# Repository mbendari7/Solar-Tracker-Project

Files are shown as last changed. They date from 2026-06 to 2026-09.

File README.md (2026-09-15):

# Solar Tracker Project

An active solar tracking system designed to optimize photovoltaic energy collection by continuously aligning solar panels with the most intense light source. This repository contains the complete project files, including custom PCB schematics, C++ firmware, and 3D-printable mechanical assemblies. 

The system utilizes closed-loop control, reading environmental light gradients through an array of sensors and actuating motors to maintain optimal panel orientation.

## Project Architecture

The project is divided into three main engineering domains: electrical hardware, mechanical design, and embedded firmware. 

### 1. Hardware and Electronics
The circuit design and PCB layouts were developed using KiCad. The hardware system is responsible for signal acquisition and motor power distribution.

*   **Microcontroller:** Arduino-compatible MCU for processing ADC readings and generating PWM control signals.
*   **Sensors:** Light Dependent Resistors (LDRs) arranged in a directional array with voltage divider networks to measure horizontal and vertical light differentials.
*   **Actuators:** Servos (or stepper motors) to control the pan (azimuth) and tilt (elevation) axes.
*   **Power Management:** Isolated power routing to prevent motor current spikes from inducing noise or brownouts on the logic circuit.
*   **Design Files:** Schematics, PCB layouts, and Gerber files are located in the `hardware/` directory.

### 2. Embedded Firmware
The control logic is written entirely in C++ and focuses on efficiency and preventing mechanical jitter. 

*   **Platform:** C++ (compiled via Arduino IDE or PlatformIO).
*   **Control Loop:** The firmware continuously polls the analog pins connected to the LDRs, calculates the light differential across the axes, and updates motor positions accordingly.
*   **Hysteresis Implementation:** A software-defined deadband is included to filter out minor lighting fluctuations (like passing clouds or sensor noise). This prevents continuous, unnecessary motor twitching, which saves power and reduces mechanical wear.
*   **Source Files:** All code, including headers and main operational logic, can be found in the `firmware/` directory.

### 3. Mechanical Design
The physical chassis is custom-designed for structural rigidity and minimal weight, ensuring the motors do not experience excessive torque loads. 

*   **Fabrication:** Designed for Fused Deposition Modeling (FDM) 3D printing. PLA or PETG is recommended for durability.
*   **Components:** Includes the base mount, azimuth rotation brackets, elevation tilt brackets, and the solar panel mounting plate. A cross-shaped LDR shadow shield is also included to cast distinct shadows over the sensors when the panel is not perfectly aligned.
*   **CAD Files:** STL files and step files are provided in the `cad/` directory.

## Repository Structure

├── cad/                  # 3D printable models (.STL files for chassis and mounts)
├── hardware/             # KiCad schematic files, PCB layouts, and gerbers
├── firmware/             # C++ source code for the microcontroller
├── docs/                 # Wiring diagrams and supplemental documentation
└── README.md             # Project overview

## Setup and Assembly

### Mechanical Assembly
1. Print all components located in the `cad/` directory with a minimum of 20% infill for structural integrity.
2. Assemble the base and mount the azimuth motor.
3. Attach the elevation bracket and corresponding motor.
4. Mount the LDR array and attach the cross-shield to ensure accurate differential shading.

### Electronics Wiring
1. Open the KiCad schematics in the `hardware/` folder to review the pinout.
2. Wire the LDR voltage dividers to the analog input pins of your MCU.
3. Connect the motor control lines to the designated PWM output pins.
4. Ensure the motors are powered by an adequate external power supply with a common ground shared with the MCU.

### Firmware Flashing
1. Open the `firmware/` directory in your preferred IDE.
2. Verify that the assigned pin definitions in the header files match your physical wiring.
3. Adjust the threshold and delay variables if your specific ambient lighting environment requires more or less sensitivity.
4. Compile and upload the code to the microcontroller.

## Future Improvements

*   Implementation of real-time clock (RTC) modules for predictive solar tracking based on time of day and geographical coordinates.
*   Integration of current and voltage sensors to log actual power generation data.
*   Migrating from servo motors to precision stepper motors for larger panel handling.

## License

This project is open-source. Feel free to fork the repository, submit pull requests, or adapt the designs for your own applications.

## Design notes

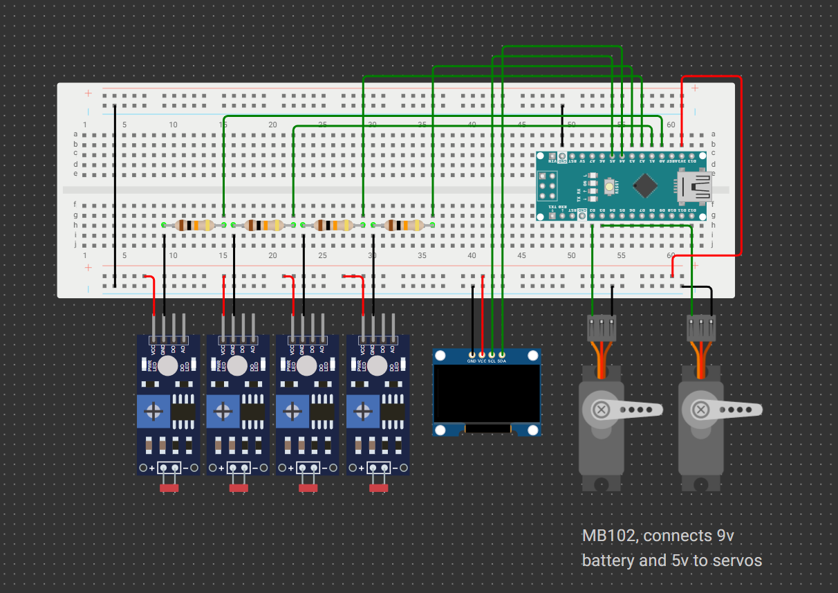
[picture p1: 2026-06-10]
Diagrams/Visual Circuit Diagram.png

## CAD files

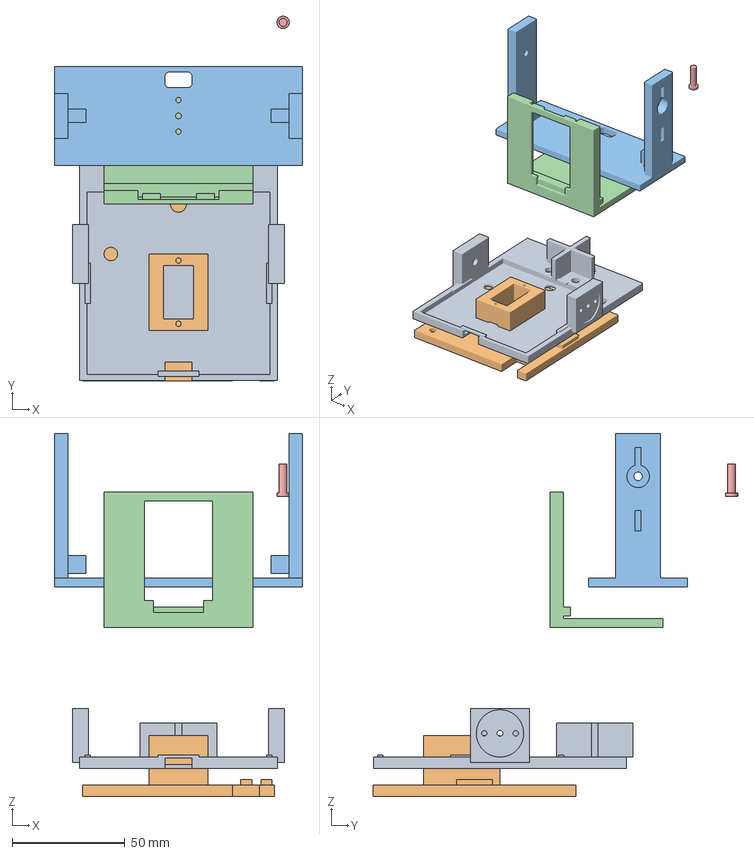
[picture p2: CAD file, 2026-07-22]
CAD and STL/CSP_solar_tracker_FINAL_all-in-one (5).3mf
110.0 x 161.7 x 161.0 mm
solar_tracker_FINAL_all-in-one (5).stl
solar_tracker_FINAL_all-in-one (5).stl 1
solar_tracker_FINAL_all-in-one (5).stl 2
solar_tracker_FINAL_all-in-one (5).stl 3
solar_tracker_FINAL_all-in-one (5).stl 4

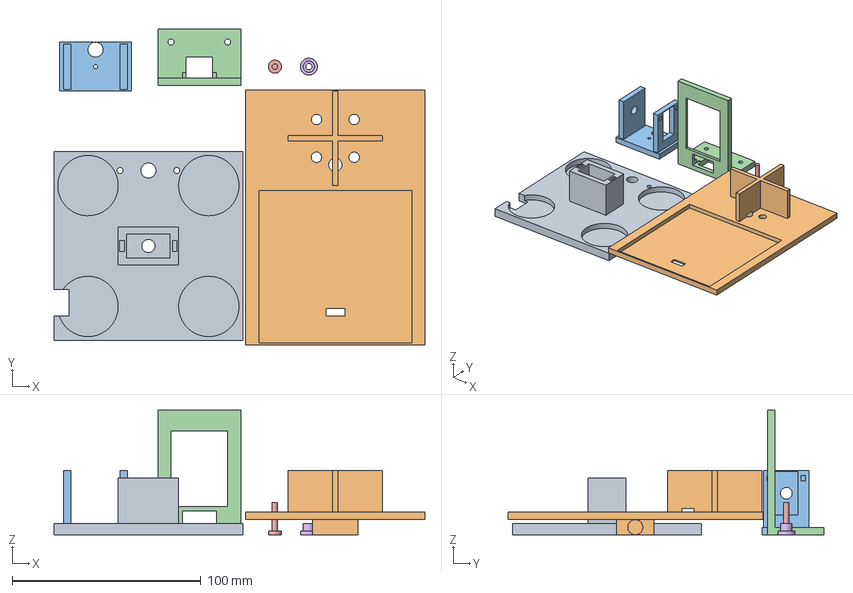
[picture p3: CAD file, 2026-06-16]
CAD and STL/solar_tracker_ALL.step
196.5 x 167.5 x 66.0 mm

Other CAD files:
CAD and STL/solar_tracker_ALL.SLDASM

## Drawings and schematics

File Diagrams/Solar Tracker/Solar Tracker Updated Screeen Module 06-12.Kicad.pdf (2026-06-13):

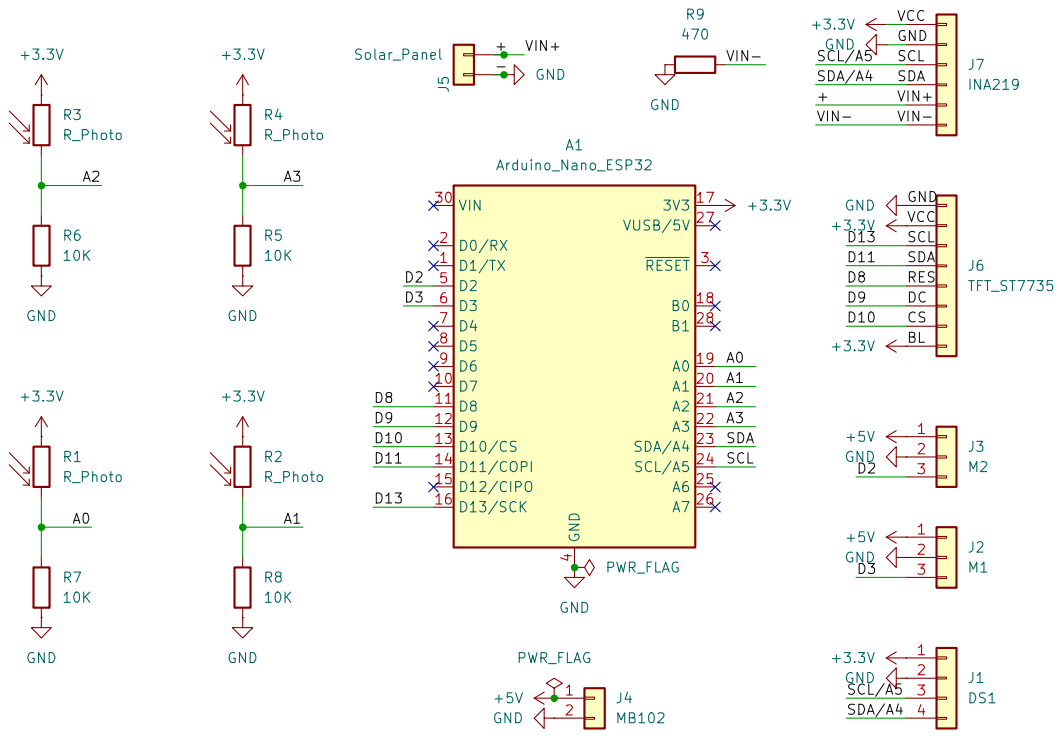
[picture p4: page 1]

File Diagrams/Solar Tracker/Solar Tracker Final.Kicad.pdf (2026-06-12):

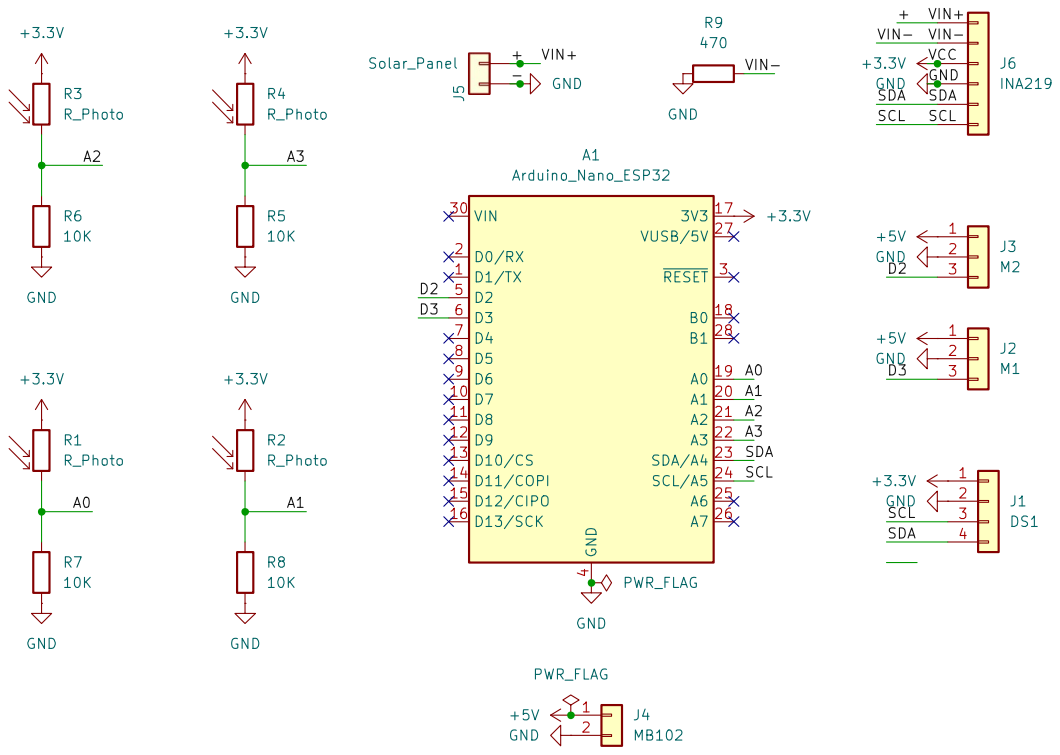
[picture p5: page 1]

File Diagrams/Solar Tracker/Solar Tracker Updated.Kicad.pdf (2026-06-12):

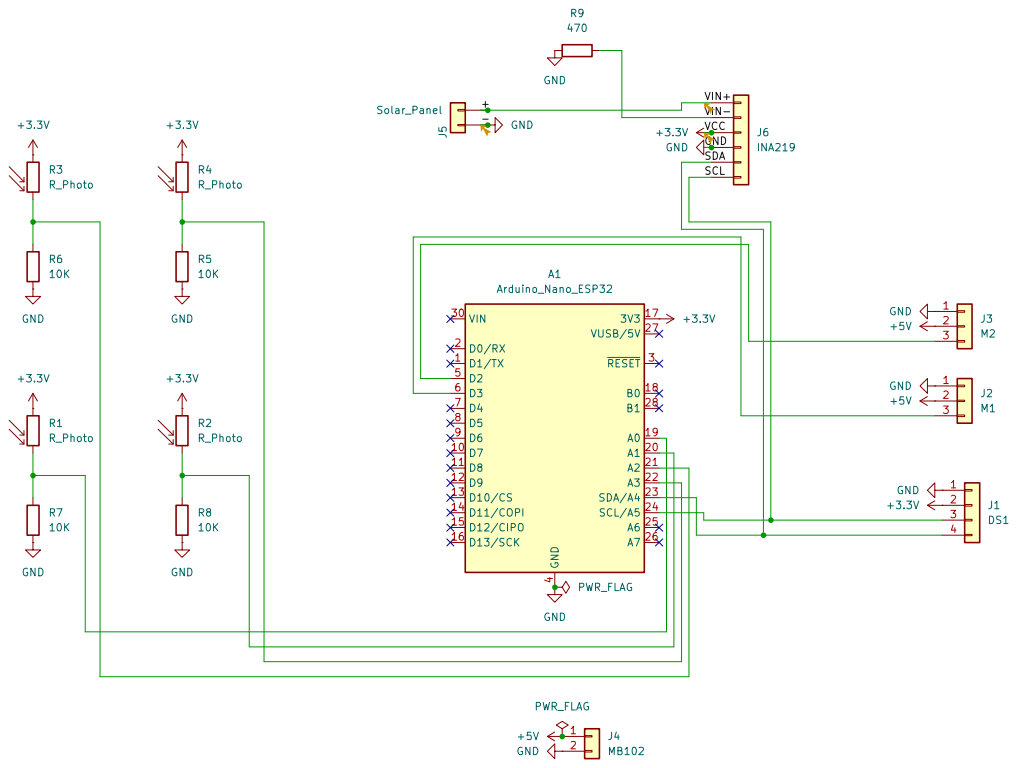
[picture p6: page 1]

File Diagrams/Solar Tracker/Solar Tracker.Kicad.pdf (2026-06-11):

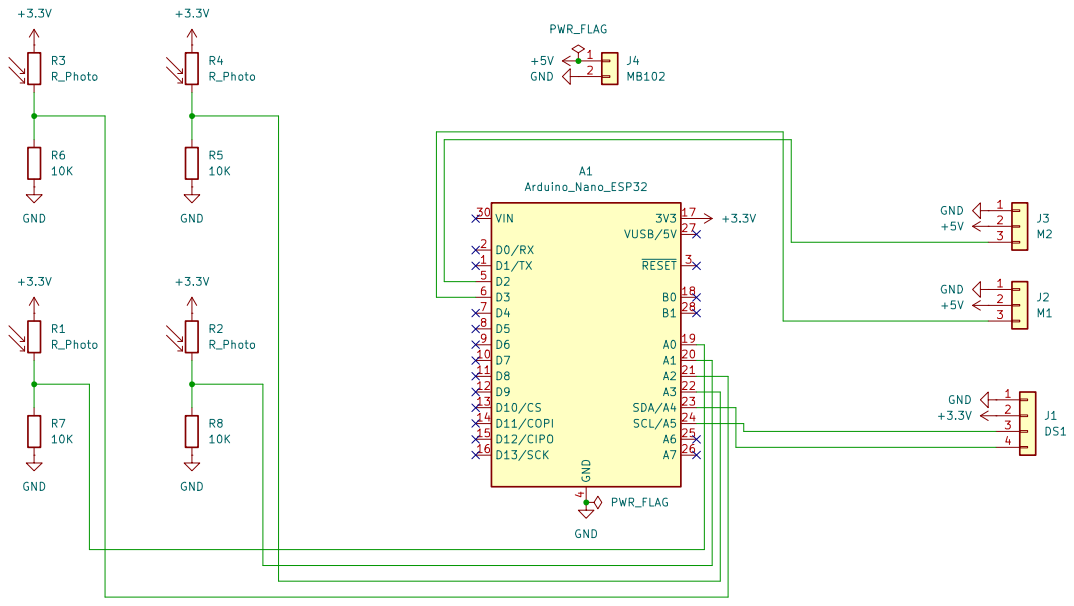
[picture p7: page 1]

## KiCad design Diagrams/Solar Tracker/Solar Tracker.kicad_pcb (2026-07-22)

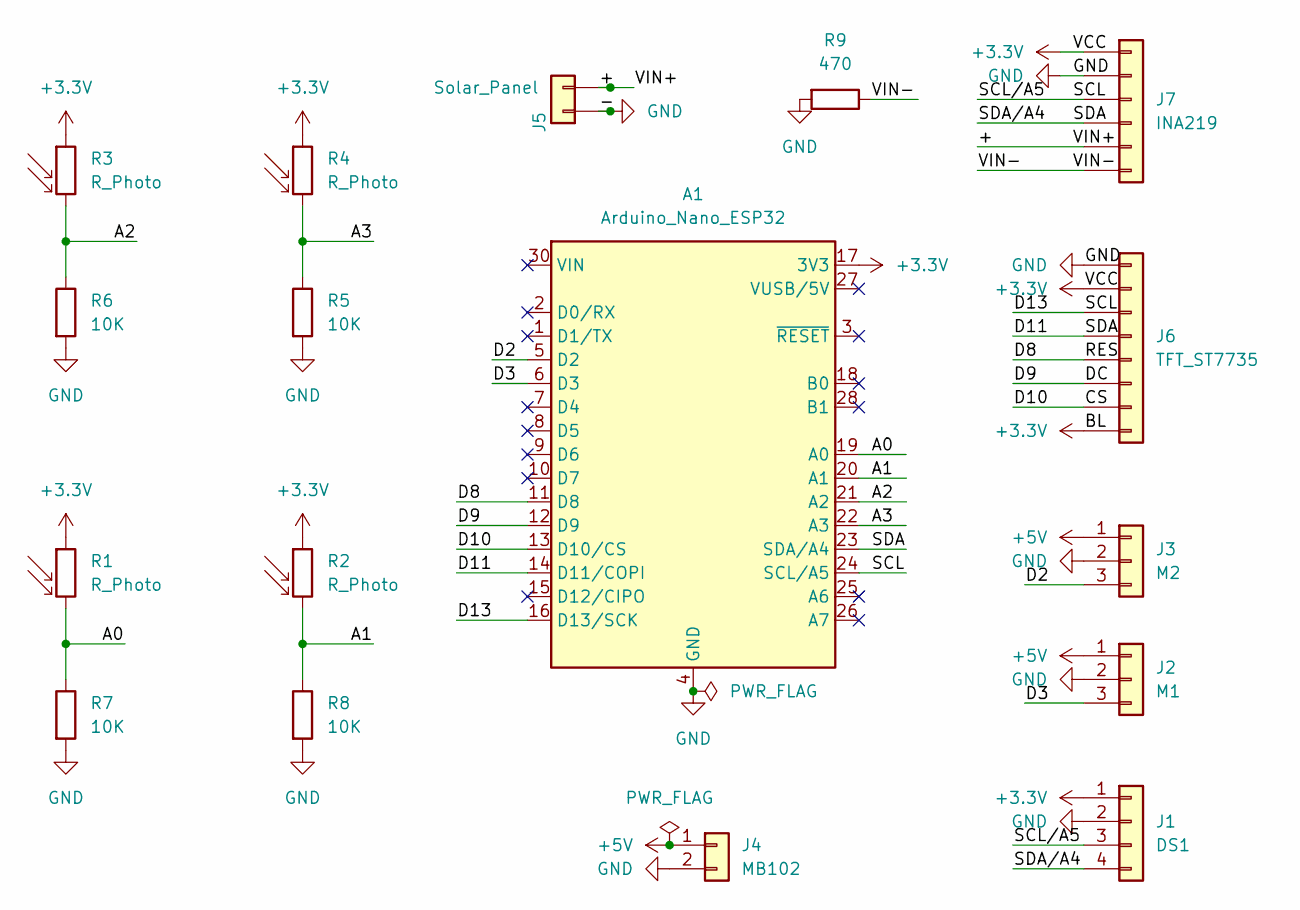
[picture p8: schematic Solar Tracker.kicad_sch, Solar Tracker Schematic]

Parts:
A1: Arduino_Nano_ESP32; Arduino_Nano
J1: DS1; PinHeader_1x04_P2.54mm_Vertical
J2: M1; PinHeader_1x03_P2.54mm_Vertical
J3: M2; PinHeader_1x03_P2.54mm_Vertical
J4: MB102; TerminalBlock_Phoenix_MKDS-1,5-2-5.08_1x02_P5.08mm_Horizont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
J5: Solar_Panel; TerminalBlock_Phoenix_MKDS-1,5-2-5.08_1x02_P5.08mm_Horizont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
J6: TFT_ST7735; PinHeader_1x08_P2.54mm_Vertical
J7: INA219; PinHeader_1x06_P2.54mm_Vertical
R1, R2, R3, R4: R_Photo; R_LDR_5.1x4.3mm_P3.4mm_Vertical
R5, R6, R7, R8: 10K; R_Axial_DIN0207_L6.3mm_D2.5mm_P10.16mm_Horizontal
R9: 470; R_Axial_DIN0207_L6.3mm_D2.5mm_P10.16mm_Horizontal

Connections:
+3.3V: A1.17 (3V3), J1.1, J6.2, J6.8, J7.1, R1.1, R2.1, R3.1, R4.1
+5V: J2.1, J3.1, J4.1
/+: J5.2, J7.5
/A0: A1.19 (A0), R1.2, R7.1
/A1: A1.20 (A1), R2.2, R8.1
/A2: A1.21 (A2), R3.2, R6.1
/A3: A1.22 (A3), R4.2, R5.1
/CS: A1.13 (D10/CS), J6.7
/D2: A1.5 (D2), J3.3
/D3: A1.6 (D3), J2.3
/D8: A1.11 (D8), J6.5
/D9: A1.12 (D9), J6.6
/D11: A1.14 (D11/COPI), A1.23 (SDA/A4), J1.4, J6.4, J7.4
/D13: A1.16 (D13/SCK), A1.24 (SCL/A5), J1.3, J6.3, J7.3
/VIN-: J7.6, R9.1
GND: A1.4 (GND), A1.29 (GND), J1.2, J2.2, J3.2, J4.2, J5.1, J6.1, J7.2, R5.2, R6.2, R7.2, R8.2, R9.2

Board: 2 copper layers, 17 parts (0 on the bottom side), 16 nets, no tracks yet.

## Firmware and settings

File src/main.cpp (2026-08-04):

/*
  DUAL-AXIS SOLAR TRACKER + POWER LOGGER + WIFI CONTROL PANEL
  Arduino Nano ESP32
*/

#include <string.h>
#include <Wire.h>
#include <SPI.h>
#include <Adafruit_GFX.h>
#include <Adafruit_ST7735.h>
#include <Adafruit_INA219.h>
#include <ESP32Servo.h>
#include <WiFi.h>
#include <WebServer.h>

// --- REVERTED TO EXPLICIT GPIO NUMBERS ---
const int PIN_TL = 1, PIN_TR = 2, PIN_BL = 3, PIN_BR = 4;
const int PAN_PIN = 5, TILT_PIN = 6;
#define TFT_CS 21
#define TFT_DC 18
#define TFT_RST 17
#define TFT_BL 10
#define TFT_SCLK 48
#define TFT_MOSI 38
#define I2C_SDA 11
#define I2C_SCL 12
#define TFT_TAB INITR_BLACKTAB
#define RAIL33_PIN 13
#define RAIL5_PIN 14
#define RAIL5_FACTOR 3.136f
// -----------------------------------------

Adafruit_ST7735 tft = Adafruit_ST7735(TFT_CS, TFT_DC, TFT_MOSI, TFT_SCLK, TFT_RST);
Adafruit_INA219 ina219;
Servo panServo, tiltServo;

const char *AP_SSID = "SolarTracker";
const char *AP_PASS = "track1234";
WebServer server(80);

const int SETTLE_MS = 20, ANGLE_MIN = 10, ANGLE_MAX = 170, PAN_DIR = +1, TILT_DIR = +1;
const int STALL_CYCLES = 40, PARK_PAN = ANGLE_MIN, PARK_TILT = 60;
const unsigned long DRAW_EVERY = 400;
const unsigned long SERIAL_EVERY = 1000;

int deadzone = 60;
int stepDeg = 1;
int darkLevel = 350;
int smoothPct = 30;
int fixedPan = 90;
int fixedTilt = 90;

enum Mode
{
  AUTO,
  FIXEDMODE,
  MANUAL
};
Mode mode = AUTO;
int manualPan = 90, manualTilt = 90;
bool isNight = false;
const char *stateLabel = "TRACKING";

int panAngle = 90, tiltAngle = 90;
int rawTL, rawTR, rawBL, rawBR;
float tl = 0, tr = 0, bl = 0, br = 0;
int hErr, vErr, panStall = 0, tiltStall = 0;
bool panStalled = false, tiltStalled = false;

float busV = 0, current_mA = 0, power_mW = 0;
bool inaOK = false;
char i2cList[64] = "";
bool servosAttached = false;
float rail33 = 0, rail5 = 0;
double energyTrack_mWh = 0, energyFixed_mWh = 0, msTrack = 0, msFixed = 0;
unsigned long lastEnergyMs = 0, lastDrawMs = 0, lastSerialMs = 0;
bool layoutDrawn = false;

void readSensors();
void updateDisplay();
void i2cScan();
void serialStatus();
void drawLayout();
uint16_t stateColor();
float gainPct();
const char *modeName();
void handleRoot();
void handleData();
void handleMode();
void handleMove();
void handleSet();
void handleReset();
void handleServoTest();

const char PAGE[] = R"HTML(
<!doctype html><html><head><meta charset=utf-8>
<meta name=viewport content="width=device-width,initial-scale=1"><title>Solar Tracker</title>
<style>
*{box-sizing:border-box}body{font-family:system-ui,Segoe UI,Roboto,sans-serif;
background:linear-gradient(160deg,#0a0e15,#0f1722);color:#e6eef7;margin:0 auto;padding:18px;max-width:560px}
h1{font-size:20px;margin:0;display:flex;align-items:center;gap:8px}
.sub{color:#6f8398;font-size:12px;margin:2px 0 14px}
.badge{font-size:12px;font-weight:800;padding:4px 10px;border-radius:20px;color:#06222a}
.card{background:#121b27;border:1px solid #1e2c3c;border-radius:14px;padding:16px;margin:12px 0;box-shadow:0 4px 14px rgba(0,0,0,.25)}
.label{color:#7d92a6;font-size:12px;text-transform:uppercase;letter-spacing:.5px}
.big{font-size:40px;font-weight:800;color:#39d98a;line-height:1.1}.unit{font-size:16px;color:#7d92a6;font-weight:600}
.gain{font-size:30px;font-weight:800;color:#f5b301}
.row{display:flex;justify-content:space-between;align-items:center;margin:7px 0;font-size:14px}.k{color:#7d92a6}.v{font-weight:600}
canvas{width:100%;height:90px;display:block;margin-top:10px}
.modes{display:flex;gap:8px}.modes button{flex:1;padding:11px;border:1px solid #27384b;border-radius:10px;background:#16212f;color:#cfe0f0;font-weight:700;font-size:14px}
.modes button.on{background:#39d98a;color:#06222a;border-color:#39d98a}
.slider{margin:12px 0}.slider .top{display:flex;justify-content:space-between;font-size:13px;margin-bottom:4px}
input[type=range]{width:100%;accent-color:#39d98a}
.btn{width:100%;padding:12px;border:0;border-radius:10px;background:#27384b;color:#cfe0f0;font-weight:700;font-size:14px;margin-top:6px}
.hide{display:none}.grid{display:grid;grid-template-columns:1fr 1fr;gap:10px;margin-top:8px}
.stat{background:#0e1722;border:1px solid #1c2a3a;border-radius:10px;padding:10px}.stat .n{font-size:18px;font-weight:700}
</style></head><body>
<h1>&#9728;&#65039; Solar Tracker <span id=badge class=badge>--</span></h1>
<div class=sub>live control panel &middot; 192.168.4.1</div>

<div class=card><div class=label>Power now</div>
<div class=big id=power>--<span class=unit> mW</span></div>
<canvas id=spark width=520 height=90></canvas></div>

<div class=card>
<div class=modes>
<button id=mAuto onclick="setMode('auto')">Auto</button>
<button id=mFixed onclick="setMode('fixed')">Fixed</button>
<button id=mManual onclick="setMode('manual')">Manual</button></div>
<div id=manual class=hide>
<div class=slider><div class=top><span class=k>Pan</span><span id=mpL>90&deg;</span></div>
<input type=range id=mp min=10 max=170 value=90 oninput="move()"></div>
<div class=slider><div class=top><span class=k>Tilt</span><span id=mtL>90&deg;</span></div>
<input type=range id=mt min=10 max=170 value=90 oninput="move()"></div></div></div>

<div class=card><div class=label>Tracking vs Fixed</div>
<div class=gain id=gain>--</div>
<div class=grid>
<div class=stat><div class=k>Track avg</div><div class=n id=pT>--</div></div>
<div class=stat><div class=k>Fixed avg</div><div class=n id=pF>--</div></div>
<div class=stat><div class=k>Energy track</div><div class=n id=eT>--</div></div>
<div class=stat><div class=k>Energy fixed</div><div class=n id=eF>--</div></div></div>
<button class=btn onclick="reset()">Reset comparison</button></div>

<div class=card>
<div class=row><span class=k>State</span><span class=v id=state>--</span></div>
<div class=row><span class=k>Voltage</span><span class=v id=volts>--</span></div>
<div class=row><span class=k>Pan / Tilt</span><span class=v id=ang>--</span></div>
<div class=row><span class=k>Sensors TL TR BL BR</span><span class=v id=sens>--</span></div></div>

<div class=card><div class=label>Diagnostics</div>
<div class=row><span class=k>I2C devices found</span><span class=v id=i2c>--</span></div>
<div class=row><span class=k>INA219</span><span class=v id=ina>--</span></div>
<div class=row><span class=k>Servos attached</span><span class=v id=sv>--</span></div>
<div class=row><span class=k>3.3V rail (wire to A6)</span><span class=v id=r33>--</span></div>
<div class=row><span class=k>5V rail (divider to A7)</span><span class=v id=r5>--</span></div>
<button class=btn onclick="servoTest()">Test servos now (forced sweep)</button></div>

<div class=card><div class=label>Tuning (live)</div>
<div class=slider><div class=top><span class=k>Deadzone</span><span id=dzL>--</span></div>
<input type=range id=dz min=5 max=300 oninput="setv('deadzone','dz','dzL','')"></div>
<div class=slider><div class=top><span class=k>Step size</span><span id=stL>--</span></div>
<input type=range id=st min=1 max=5 oninput="setv('step','st','stL','')"></div>
<div class=slider><div class=top><span class=k>Smoothing</span><span id=smL>--</span></div>
<input type=range id=sm min=5 max=90 oninput="setv('smooth','sm','smL','%')"></div>
<div class=slider><div class=top><span class=k>Night level</span><span id=dkL>--</span></div>
<input type=range id=dk min=0 max=2000 oninput="setv('dark','dk','dkL','')"></div>
<div class=slider><div class=top><span class=k>Fixed pan</span><span id=fpL>--</span></div>
<input type=range id=fp min=10 max=170 oninput="setv('fpan','fp','fpL','&deg;')"></div>
<div class=slider><div class=top><span class=k>Fixed tilt</span><span id=ftL>--</span></div>
<input type=range id=ft min=10 max=170 oninput="setv('ftilt','ft','ftL','&deg;')"></div></div>

<script>
let hist=[],first=true,last={},$=id=>document.getElementById(id);
const bc={TRACKING:'#39d98a',NIGHT:'#6aa6ff',FIXED:'#f5b301',MANUAL:'#ff7ac6'};
async function tick(){try{
let d=await(await fetch('/data')).json();last=d;
$('power').innerHTML=d.power.toFixed(1)+'<span class=unit> mW</span>';
$('badge').textContent=d.state;$('badge').style.background=bc[d.state]||'#7d92a6';
$('gain').textContent=(d.gain>=0?'+':'')+d.gain.toFixed(1)+'%';
$('pT').textContent=d.pTrack.toFixed(1)+' mW';$('pF').textContent=d.pFixed.toFixed(1)+' mW';
$('eT').textContent=d.eTrack.toFixed(2)+' mWh';$('eF').textContent=d.eFixed.toFixed(2)+' mWh';
$('state').textContent=d.state+(d.stall?'  (stall)':'');
$('volts').textContent=d.volts.toFixed(2)+' V';$('ang').textContent=d.pan+'\u00b0 / '+d.tilt+'\u00b0';
$('sens').textContent=d.s.join('  ');
$('i2c').textContent=d.i2c;
$('ina').textContent=d.ina?'FOUND':'NOT FOUND';$('ina').style.color=d.ina?'#39d98a':'#ff6b6b';
$('sv').textContent=d.sv?'yes':'NO';$('sv').style.color=d.sv?'#39d98a':'#ff6b6b';
$('r33').textContent=d.r33<0.3?'not wired':d.r33.toFixed(2)+' V';
$('r33').style.color=d.r33<0.3?'#8b98a5':(d.r33>3.0?'#39d98a':'#ff6b6b');
$('r5').textContent=d.r5<0.5?'not wired':d.r5.toFixed(2)+' V';
$('r5').style.color=d.r5<0.5?'#8b98a5':(d.r5>4.6?'#39d98a':'#ff6b6b');
['mAuto','mFixed','mManual'].forEach(x=>$(x).classList.remove('on'));
$({auto:'mAuto',fixed:'mFixed',manual:'mManual'}[d.mode]).classList.add('on');
$('manual').classList.toggle('hide',d.mode!='manual');
if(first){
 $('dz').value=d.deadzone;$('dzL').textContent=d.deadzone;
 $('st').value=d.step;$('stL').textContent=d.step;
 $('sm').value=d.smooth;$('smL').textContent=d.smooth+'%';
 $('dk').value=d.dark;$('dkL').textContent=d.dark;
 $('fp').value=d.fpan;$('fpL').innerHTML=d.fpan+'&deg;';
 $('ft').value=d.ftilt;$('ftL').innerHTML=d.ftilt+'&deg;';
 first=false;}
hist.push(d.power);if(hist.length>120)hist.shift();draw();
}catch(e){}}
function draw(){let c=$('spark'),x=c.getContext('2d'),w=c.width,h=c.height;
x.clearRect(0,0,w,h);let m=Math.max(1,...hist);x.strokeStyle='#39d98a';x.lineWidth=2;x.beginPath();
hist.forEach((v,i)=>{let px=i/119*w,py=h-(v/m)*(h-8)-4;i?x.lineTo(px,py):x.moveTo(px,py);});x.stroke();}
function setMode(m){fetch('/mode?m='+m);
 if(m=='manual'&&last.pan!=null){$('mp').value=last.pan;$('mt').value=last.tilt;
  $('mpL').innerHTML=last.pan+'&deg;';$('mtL').innerHTML=last.tilt+'&deg;';}}
function move(){let p=$('mp').value,t=$('mt').value;
 $('mpL').innerHTML=p+'&deg;';$('mtL').innerHTML=t+'&deg;';fetch('/move?pan='+p+'&tilt='+t);}
function setv(key,sid,lid,suf){let v=$(sid).value;$(lid).innerHTML=v+suf;fetch('/set?k='+key+'&v='+v);}
function reset(){fetch('/reset');}
function servoTest(){fetch('/servotest');}
setInterval(tick,1000);tick();
</script></body></html>
)HTML";

void setup()
{
  Serial.begin(115200);
  delay(3000);

  Serial.println("Booting up...");
  analogReadResolution(12);
  pinMode(TFT_BL, OUTPUT);
  digitalWrite(TFT_BL, HIGH);

  Wire.begin(I2C_SDA, I2C_SCL);
  i2cScan();
  inaOK = ina219.begin();
  if (inaOK)
  {
    ina219.setCalibration_16V_400mA();
    Serial.println("INA219 ready (16V / 400mA range)");
  }
  else
    Serial.println("INA219 NOT FOUND -- check SDA on A4, SCL on A5, VCC on 3.3V");

  tft.initR(TFT_TAB);
  tft.setRotation(3);

  Serial.println("Display test: red, green, blue...");
  tft.fillScreen(ST77XX_RED);
  delay(350);
  tft.fillScreen(ST77XX_GREEN);
  delay(350);
  tft.fillScreen(ST77XX_BLUE);
  delay(350);
  tft.fillScreen(ST77XX_BLACK);
  tft.setTextColor(ST77XX_YELLOW);
  tft.setTextSize(2);
  tft.setCursor(8, 28);
  tft.print("SOLAR");
  tft.setTextSize(1);
  tft.setTextColor(ST77XX_WHITE);
  tft.setCursor(8, 56);
  tft.print("WiFi: ");
  tft.print(AP_SSID);
  tft.setCursor(8, 70);
  tft.print("http://192.168.4.1");

  ESP32PWM::allocateTimer(0);
  ESP32PWM::allocateTimer(1);
  ESP32PWM::allocateTimer(2);
  ESP32PWM::allocateTimer(3);
  panServo.setPeriodHertz(50);
  tiltServo.setPeriodHertz(50);
  panServo.attach(PAN_PIN, 500, 2400);
  tiltServo.attach(TILT_PIN, 500, 2400);
  servosAttached = panServo.attached() && tiltServo.attached();
  Serial.println(servosAttached ? "Servos attached" : "SERVO ATTACH FAILED");
  panServo.write(panAngle);
  tiltServo.write(tiltAngle);

  WiFi.softAP(AP_SSID, AP_PASS);
  server.on("/", handleRoot);
  server.on("/data", handleData);
  server.on("/mode", handleMode);
  server.on("/move", handleMove);
  server.on("/set", handleSet);
  server.on("/reset", handleReset);
  server.on("/servotest", handleServoTest);
  server.begin();
  layoutDrawn = false;

  lastEnergyMs = millis();
  delay(1200);
}

void loop()
{
  readSensors();
  float avg = (tl + tr + bl + br) / 4.0;

  if (inaOK)
  {
    busV = ina219.getBusVoltage_V();
    current_mA = ina219.getCurrent_mA();
    power_mW = ina219.getPower_mW();
    if (power_mW < 0)
      power_mW = 0;
  }

  unsigned long now = millis();
  double dms = now - lastEnergyMs;
  lastEnergyMs = now;
  if (mode == AUTO)
  {
    energyTrack_mWh += power_mW * (dms / 3600000.0);
    msTrack += dms;
  }
  else if (mode == FIXEDMODE)
  {
    energyFixed_mWh += power_mW * (dms / 3600000.0);
    msFixed += dms;
  }

  isNight = false;
  if (mode == MANUAL)
  {
    panAngle = manualPan;
    tiltAngle = manualTilt;
    stateLabel = "MANUAL";
    panStalled = tiltStalled = false;
  }
  else if (mode == FIXEDMODE)
  {
    panAngle = fixedPan;
    tiltAngle = fixedTilt;
    stateLabel = "FIXED";
    panStalled = tiltStalled = false;
  }
  else
  {
    if (avg < darkLevel)
    {
      panAngle = PARK_PAN;
      tiltAngle = PARK_TILT;
      stateLabel = "NIGHT";
      isNight = true;
      panStalled = tiltStalled = false;
    }
    else
    {
      stateLabel = "TRACKING";
      hErr = ((tl + bl) / 2) - ((tr + br) / 2);
      vErr = ((tl + tr) / 2) - ((bl + br) / 2);
      int panNudge = (abs(hErr) > deadzone) ? PAN_DIR * ((hErr > 0) ? stepDeg : -stepDeg) : 0;
      int tiltNudge = (abs(vErr) > deadzone) ? TILT_DIR * ((vErr > 0) ? stepDeg : -stepDeg) : 0;

      if ((panAngle >= ANGLE_MAX && panNudge > 0) || (panAngle <= ANGLE_MIN && panNudge < 0))
      {
        if (++panStall > STALL_CYCLES)
          panStalled = true;
        panNudge = 0;
      }
      else
      {
        panStall = 0;
        panStalled = false;
      }
      if ((tiltAngle >= ANGLE_MAX && tiltNudge > 0) || (tiltAngle <= ANGLE_MIN && tiltNudge < 0))
      {
        if (++tiltStall > STALL_CYCLES)
          tiltStalled = true;
        tiltNudge = 0;
      }
      else
      {
        tiltStall = 0;
        tiltStalled = false;
      }
      panAngle = constrain(panAngle + panNudge, ANGLE_MIN, ANGLE_MAX);
      tiltAngle = constrain(tiltAngle + tiltNudge, ANGLE_MIN, ANGLE_MAX);
    }
  }

  panServo.write(panAngle);
  tiltServo.write(tiltAngle);

  if (now - lastDrawMs >= DRAW_EVERY)
  {
    updateDisplay();
    lastDrawMs = now;
  }
  if (now - lastSerialMs >= SERIAL_EVERY)
  {
    rail33 = analogReadMilliVolts(RAIL33_PIN) / 1000.0f;
    rail5 = analogReadMilliVolts(RAIL5_PIN) * RAIL5_FACTOR / 1000.0f;
    serialStatus();
    lastSerialMs = now;
  }
  server.handleClient();
  delay(SETTLE_MS);
}

void i2cScan()
{
  Serial.println("I2C scan:");
  int found = 0;
  for (uint8_t addr = 1; addr < 127; addr++)
  {
    Wire.beginTransmission(addr);
    if (Wire.endTransmission() == 0)
    {
      Serial.print("  device at 0x");
      Serial.println(addr, HEX);
      char one[10];
      snprintf(one, sizeof(one), "%s0x%02X", found ? " " : "", addr);
      strncat(i2cList, one, sizeof(i2cList) - strlen(i2cList) - 1);
      found++;
    }
  }
  if (found == 0)
  {
    Serial.println("  no devices on the bus");
    snprintf(i2cList, sizeof(i2cList), "none");
  }
}

void serialStatus()
{
  Serial.print("sensors ");
  Serial.print(rawTL);
  Serial.print(" ");
  Serial.print(rawTR);
  Serial.print(" ");
  Serial.print(rawBL);
  Serial.print(" ");
  Serial.print(rawBR);
  Serial.print(" | hErr ");
  Serial.print(hErr);
  Serial.print(" vErr ");
  Serial.print(vErr);
  Serial.print(" deadzone ");
  Serial.print(deadzone);
  Serial.print(" | pan ");
  Serial.print(panAngle);
  Serial.print(" tilt ");
  Serial.print(tiltAngle);
  Serial.print(" | ");
  if (inaOK)
  {
    Serial.print(busV, 2);
    Serial.print("V ");
    Serial.print(current_mA, 2);
    Serial.print("mA ");
    Serial.print(power_mW, 2);
    Serial.print("mW");
  }
  else
    Serial.print("INA219 offline");
  Serial.print(" | ");
  Serial.print(stateLabel);
  Serial.print(" / ");
  Serial.println(modeName());
}

void readSensors()
{
  rawTL = analogRead(PIN_TL);
  rawTR = analogRead(PIN_TR);
  rawBL = analogRead(PIN_BL);
  rawBR = analogRead(PIN_BR);
  float a = smoothPct / 100.0;
  tl += (rawTL - tl) * a;
  tr += (rawTR - tr) * a;
  bl += (rawBL - bl) * a;
  br += (rawBR - br) * a;
}

uint16_t stateColor()
{
  if (mode == MANUAL)
    return 0xFB56;
  if (mode == FIXEDMODE)
    return 0xFD20;
  if (isNight)
    return 0x5BDF;
  return 0x07E0;
}

const char *modeName() { return mode == AUTO ? "auto" : mode == FIXEDMODE ? "fixed"
                                                                          : "manual"; }

float gainPct()
{
  double hT = msTrack / 3600000.0, hF = msFixed / 3600000.0;
  double pT = hT > 0 ? energyTrack_mWh / hT : 0;
  double pF = hF > 0 ? energyFixed_mWh / hF : 0;
  return pF > 0 ? (float)((pT - pF) / pF * 100.0) : 0;
}

void drawLayout()
{
  tft.fillScreen(ST77XX_BLACK);
  tft.setTextSize(2);
  tft.setTextColor(ST77XX_YELLOW);
  tft.setCursor(4, 2);
  tft.print("SOLAR");
  tft.setTextSize(1);
  tft.setTextColor(0x7BEF);
  tft.setCursor(4, 26);
  tft.print("POWER");
  tft.setTextColor(0x7BEF);
  tft.setCursor(4, 60);
  tft.print("Volt");
  tft.setCursor(92, 60);
  tft.print("P/T");
  tft.setCursor(4, 80);
  tft.print("E trk");
  tft.setCursor(4, 92);
  tft.print("E fix");
  tft.setCursor(4, 104);
  tft.print("Gain");
  tft.setTextColor(0x5BDF);
  tft.setCursor(4, 120);
  tft.print("WiFi ");
  tft.print(AP_SSID);
  tft.print(" .4.1");
  layoutDrawn = true;
}

void updateDisplay()
{
  if (!layoutDrawn)
    drawLayout();
  uint16_t col = stateColor();
  tft.fillRoundRect(92, 2, 64, 16, 3, col);
  tft.setTextSize(1);
  tft.setTextColor(ST77XX_BLACK);
  tft.setCursor(97, 6);
  tft.print(stateLabel);
  tft.setTextSize(2);
  tft.setTextColor(ST77XX_GREEN, ST77XX_BLACK);
  tft.setCursor(4, 36);
  tft.print(power_mW, 1);
  tft.setTextSize(1);
  tft.print(" mW   ");
  tft.setTextColor(ST77XX_WHITE, ST77XX_BLACK);
  tft.setCursor(40, 60);
  tft.print(busV, 2);
  tft.print("V  ");
  tft.setCursor(116, 60);
  tft.print(panAngle);
  tft.print("/");
  tft.print(tiltAngle);
  tft.print("  ");
  tft.setTextColor(ST77XX_CYAN, ST77XX_BLACK);
  tft.setCursor(46, 80);
  tft.print(energyTrack_mWh, 2);
  tft.print("  ");
  tft.setCursor(46, 92);
  tft.print(energyFixed_mWh, 2);
  tft.print("  ");
  tft.setTextColor(0xFD20, ST77XX_BLACK);
  tft.setCursor(46, 104);
  tft.print(gainPct(), 1);
  tft.print("%  ");
}

void handleRoot() { server.send(200, "text/html", PAGE); }

void handleData()
{
  double hT = msTrack / 3600000.0, hF = msFixed / 3600000.0;
  double pT = hT > 0 ? energyTrack_mWh / hT : 0;
  double pF = hF > 0 ? energyFixed_mWh / hF : 0;
  char buf[760];
  snprintf(buf, sizeof(buf),
           "{\"power\":%.1f,\"volts\":%.2f,\"pan\":%d,\"tilt\":%d,"
           "\"eTrack\":%.3f,\"eFixed\":%.3f,\"pTrack\":%.1f,\"pFixed\":%.1f,\"gain\":%.1f,"
           "\"s\":[%d,%d,%d,%d],\"state\":\"%s\",\"mode\":\"%s\",\"stall\":%s,"
           "\"deadzone\":%d,\"step\":%d,\"smooth\":%d,\"dark\":%d,\"fpan\":%d,\"ftilt\":%d,"
           "\"i2c\":\"%s\",\"ina\":%s,\"sv\":%s,\"r33\":%.2f,\"r5\":%.2f}",
           power_mW, busV, panAngle, tiltAngle, energyTrack_mWh, energyFixed_mWh, pT, pF, gainPct(),
           rawTL, rawTR, rawBL, rawBR, stateLabel, modeName(),
           (panStalled || tiltStalled) ? "true" : "false",
           deadzone, stepDeg, smoothPct, darkLevel, fixedPan, fixedTilt,
           i2cList, inaOK ? "true" : "false", servosAttached ? "true" : "false", rail33, rail5);
  server.send(200, "application/json", buf);
}

void handleMode()
{
  String m = server.arg("m");
  if (m == "auto")
    mode = AUTO;
  else if (m == "fixed")
    mode = FIXEDMODE;
  else if (m == "manual")
  {
    mode = MANUAL;
    manualPan = panAngle;
    manualTilt = tiltAngle;
  }
  server.send(200, "text/plain", "ok");
}

void handleMove()
{
  if (server.hasArg("pan"))
    manualPan = constrain(server.arg("pan").toInt(), ANGLE_MIN, ANGLE_MAX);
  if (server.hasArg("tilt"))
    manualTilt = constrain(server.arg("tilt").toInt(), ANGLE_MIN, ANGLE_MAX);
  server.send(200, "text/plain", "ok");
}

void handleSet()
{
  String k = server.arg("k");
  int v = server.arg("v").toInt();
  if (k == "deadzone")
    deadzone = constrain(v, 5, 300);
  else if (k == "step")
    stepDeg = constrain(v, 1, 5);
  else if (k == "smooth")
    smoothPct = constrain(v, 5, 90);
  else if (k == "dark")
    darkLevel = constrain(v, 0, 2000);
  else if (k == "fpan")
    fixedPan = constrain(v, ANGLE_MIN, ANGLE_MAX);
  else if (k == "ftilt")
    fixedTilt = constrain(v, ANGLE_MIN, ANGLE_MAX);
  server.send(200, "text/plain", "ok");
}

void handleServoTest()
{
  server.send(200, "text/plain", "sweeping");
  for (int a = 60; a <= 120; a += 2)
  {
    panServo.write(a);
    tiltServo.write(a);
    delay(20);
  }
  for (int a = 120; a >= 60; a -= 2)
  {
    panServo.write(a);
    tiltServo.write(a);
    delay(20);
  }
  panServo.write(90);
  tiltServo.write(90);
  manualPan = manualTilt = 90;
}

void handleReset()
{
  energyTrack_mWh = 0;
  energyFixed_mWh = 0;
  msTrack = 0;
  msFixed = 0;
  server.send(200, "text/plain", "ok");
}

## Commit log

2026-06-08 Created PlatformIO and edited it
    Editied the platformio.ini file to my specific platform of arduino nano esp32. Added screen and servo libraries as well.
2026-06-10 Add visual circuit diagram image
    Added image of a visual rough idea of the circuit
2026-06-11 Add Solar Tracker KiCad project files
    Add a new KiCad project 'Solar Tracker' under Diagrams/Solar Tracker. This commit introduces the schematic (.kicad_sch), PCB file (.kicad_pcb), project settings and preferences (.kicad_pro, .kicad_pr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
    [Solar Tracker.kicad_pcb, Solar Tracker.kicad_sch]
2026-06-11 Added Kicad PDF
    Added a PDF of the schematic.
2026-06-11 Update Solar Tracker.kicad_pro
2026-06-11 Move PlatformIO files; add solar-tracker sketch
    Rename/move PlatformIO project files to repo root (.gitignore, .vscode/extensions.json, include/, lib/, platformio.ini, test/README) and remove the old placeholder PlatformIO/src/main.cpp. Add a new 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
2026-06-12 Updated the Solar Tracker Schematic
    [Solar Tracker.kicad_sch]
2026-06-12 Updated SCH file for circuit and Netwired it
    [Solar Tracker.kicad_sch]
2026-06-13 Update Solar Tracker schematic & project files
    Add updated screen module PDF and apply multiple KiCad project/schematic updates. Changes include updating used_designators in the .kicad_pro, adding a generic 1x08 connector symbol and many schemati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
    [Solar Tracker.kicad_sch]
2026-06-16 Add CAD/STEP/STL for solar_tracker_ALL
    Add full CAD exports and mesh for the solar_tracker_ALL model: SolidWorks assembly (.SLDASM), STEP (.step) and STL (.stl) placed under 'CAD and STL/'. STEP file was exported via Open CASCADE and incl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
    [solar_tracker_ALL.SLDASM, solar_tracker_ALL.step, solar_tracker_ALL.stl]
2026-06-16 Updated Code with Wireless Network
2026-06-16 Refactor and document solar tracker firmware
    Reorganise and enrich the main firmware: expand and clarify the file header and wiring notes; add detailed comments for hardware, networking, runtime variables and web dashboard behavior; define and document pin constants (including TFT_BL) and AP credentials; initialise I2C/INA219 with a check and reserve PWM timers before attaching servos; improve loop structure with explicit steps for sensor smoothing, energy accumulation, state selection and display refresh; add helper functions (modeName, gainPct) and document web handlers. Also tighten servo/stall logic, constrain inputs, and improve display and JSON data output comments. Overall this is a r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
    [main.cpp]
2026-06-18 Add DFU upload and serial startup delay
    platformio.ini: set upload_protocol to dfu and monitor_port to COM5 to use DFU uploads and target the serial monitor port. src/main.cpp: add a 3s delay after Serial.begin and print a "Booting up..." 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
2026-07-09 Add solar tracker STL; enable USB CDC on boot
    Add final 3D model file (CAD and STL/solar_tracker_FINAL.stl) for the solar tracker. Update platformio.ini to set build_flags = -D ARDUINO_USB_CDC_ON_BOOT=1 so the Arduino USB CDC is enabled on boot (ensures serial over USB is active immediately after reset).
    [solar_tracker_FINAL.stl]
2026-07-09 Cleanup on STL files
    [CSP_solar_tracker_FINAL.stl, solar_tracker_FINAL.stl]
2026-07-22 Updated STL file
    [CSP_solar_tracker_FINAL.stl, CSP_solar_tracker_FINAL_all-in-one (5).3mf, solar_tracker_ALL.stl]
2026-07-22 Optimize TFT redraw; correct ST7735 BL pin
    Reduce display flicker by drawing a static dashboard layout once and performing small, in-place updates thereafter. Introduced layoutDrawn flag, new drawLayout() and modified updateDisplay() to use text background colors (erasing previous values) and only redraw dynamic fields and the state badge. Initialize layoutDrawn = false in setup(). Also corrected the ST7735 backlight wiring comment (BL -> D7). These changes improve refresh performance and visual stability.
    [main.cpp]
2026-07-22 Add PCB layout and assign component footprints
    Populate PCB layout with complete design including footprints for all components (resistors, LDRs, connectors, and Arduino). Assign matching footprint references in schematic to ensure consistency be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
    [Solar Tracker.kicad_pcb, Solar Tracker.kicad_sch]
2026-07-24 Add diagnostics, I2C scan, servo test, UI
    Introduce runtime diagnostics and testing: I2C bus scan (i2cScan) with i2cList, INA219 presence handling and 16V/400mA calibration, periodic serialStatus output, display color test, and servosAttached flag. Add /servotest HTTP endpoint to force a servo sweep and a Diagnostics card in the web UI showing I2C devices, INA status, and servo attachment. Make TFT init tab configurable (TFT_TAB), include diagnostics fields in /data JSON, and avoid assuming INA219 is always present. Also remove the hardcoded monitor_port from platformio.ini.
    [main.cpp]
2026-08-04 Add rail voltage sensing and pin rework
    Replace generic analog/board aliases with explicit GPIO assignments, add 3.3V and 5V rail measurement (RAIL33_PIN, RAIL5_PIN + RAIL5_FACTOR) and expose their values to the web dashboard and JSON /data. Update ST7735 constructor to use explicit MOSI/SCLK, initialize I2C with explicit SDA/SCL pins, and call i2cScan(). Read rails each second using analogReadMilliVolts and include r33/r5 in PAGE HTML/JS and server response. Misc: minor cleanup and reformatting, preserve existing behavior for tracking, servos, and INA219 calibration.
    [main.cpp]
2026-09-15 Add README for Solar Tracker Project
    This README provides an overview of the Solar Tracker Project, detailing its architecture, components, assembly instructions, and future improvements.
